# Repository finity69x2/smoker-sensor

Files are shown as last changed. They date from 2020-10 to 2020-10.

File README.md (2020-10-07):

# Smoker Sensor

This is a sensor that will read both the temperature of a smoker box and a single probe for food temperature.

It provides a webpage to display the current temperatures (updates every 10 seconds) along with communication to an MQTT broker for 
accessing the temperatures for my home automation system (Home Assistant).

It's built around a NodeMCU development board because it is lower power and provides wifi on board. It is programmmed using the Arduino-IDE.

The Arduino skecth is included here along with a schematic developed using the Fritzing app.

Here is the parts list:

| Part | Link |
| --- | --- |
| NodeMCU | https://smile.amazon.com/gp/product/B07L8W9SP3 |
| Thermocouple probe | https://smile.amazon.com/gp/product/B07JL1SN7X |
| MAX31855 breakout board for thermocouple | https://smile.amazon.com/gp/product/B07T7WY3H8 |
| panel mount thermocouple connector | https://smile.amazon.com/k-type-thermocouple-miniature-socket-connector/dp/B071SCMHRX |
| thermocouple male connector | https://smile.amazon.com/Twidec-Thermocouple-Connector-Adapter-Temperature/dp/B07PQW47BP |
| thermister probe | https://smile.amazon.com/gp/product/B07L4TQC4B |
| Thermister connector | https://smile.amazon.com/gp/product/B01ASF0GWS |
| LED's | https://smile.amazon.com/gp/product/B01AUI4W5U |
| waterproof box | https://smile.amazon.com/gp/product/B07QGS2HT4 |
| USB Power connectors | https://smile.amazon.com/gp/product/B0183KF7TM |
| capacitors | https://smile.amazon.com/gp/product/B07KRTQGL7 |
| USB extension plug | https://smile.amazon.com/gp/product/B00B5HSC20 |
| perf board | https://smile.amazon.com/gp/product/B07QL77SC5 |
| resistors | https://smile.amazon.com/gp/product/B072BL2VX1 |

You can likely get all of this cheaper on sites like Aliexpress with the attendant longer shipping times.

The sensor serves up a webpage to allow you to see the current temperatues in real time (it updates every 10 seconds) and an MQTT connection to allow you to connect to your home automation system.

I have provided two different Arduino Sketches. One that provides the MQTT connection and one that doesn't. So if you don't have the need to use MQTT then use the latter (non-MQTT) sketch.

You will need to determine the co-erfficients for the thermistor you use and what the nominal resistance is and enter that info into the Arduino sketch. the sketch also allows you to use the Beta value if that has been supplied by the manufacturer. Just uncomment whichever method you will want to use.

After the sketch is flashed to the NodeMCU initial network config is done via an AP (SmokerConnectAP) provided by the NodeMCU. Once connected to the AP then navigate 192.168.1.4 and fill in your credentials.

After the initial config is completed then the sensor will reboot and connect to your wifi network (and MQTT broker if used). You will need to go into your router to find the IP address of the sensor or however you normally find IP addresses of devices on your network.

The sensor has three status LED's - One for Power (green), One for Wifi connection status (blue) and an activity LED (red).

It uses a thermistor for measuring the food temperature and a K-type thermocouple for the smoker box temerature measurement.

Here is the schematic:

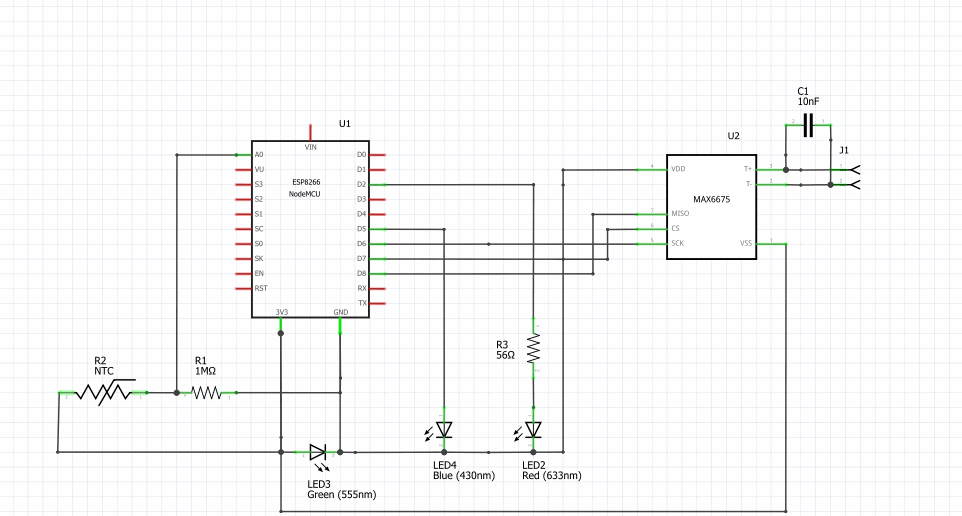
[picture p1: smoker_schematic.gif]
Schematic


Here are the pictures of the end result:

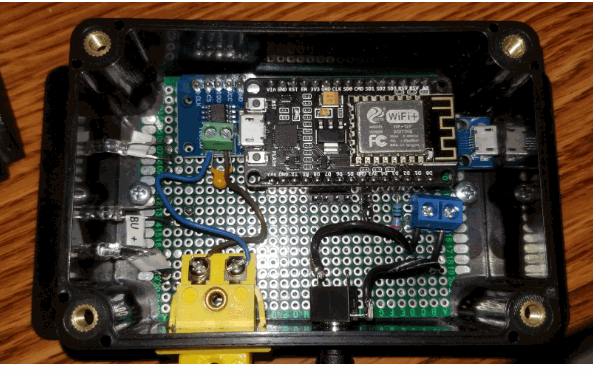
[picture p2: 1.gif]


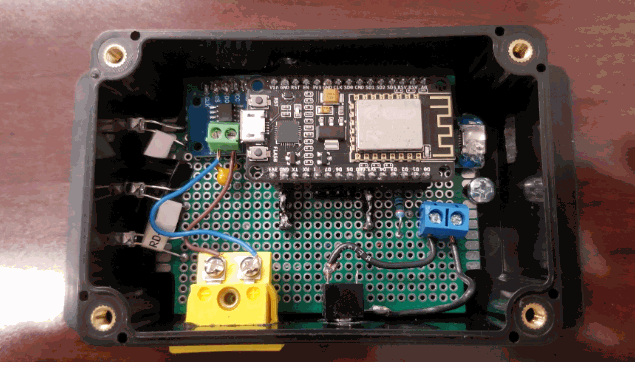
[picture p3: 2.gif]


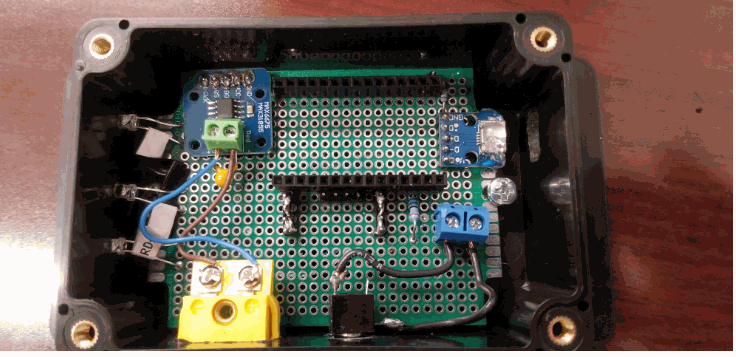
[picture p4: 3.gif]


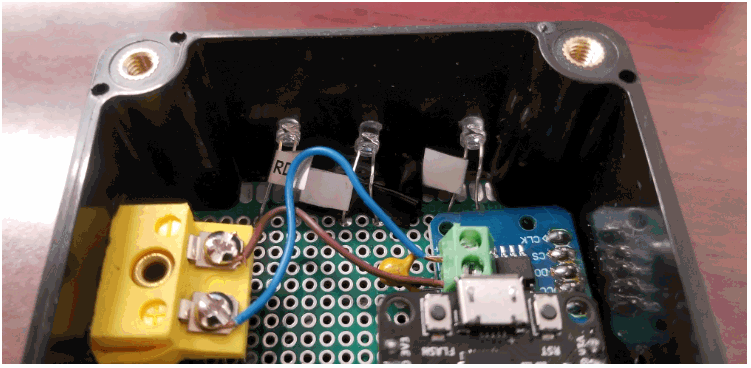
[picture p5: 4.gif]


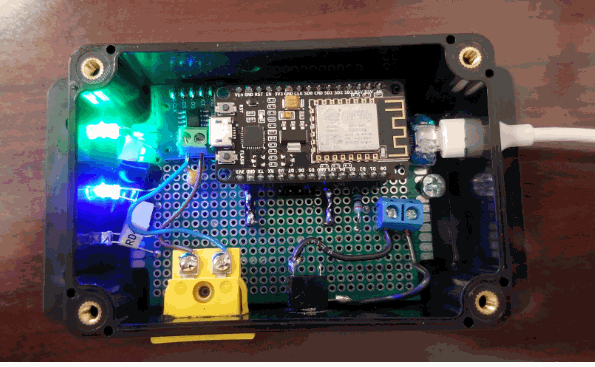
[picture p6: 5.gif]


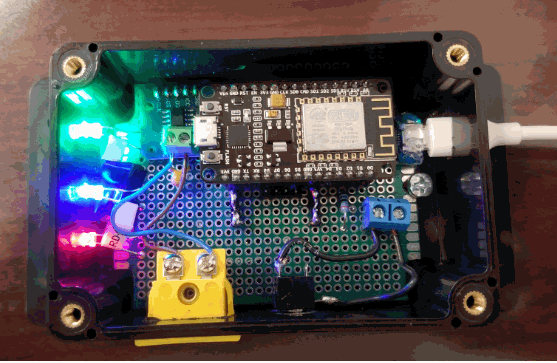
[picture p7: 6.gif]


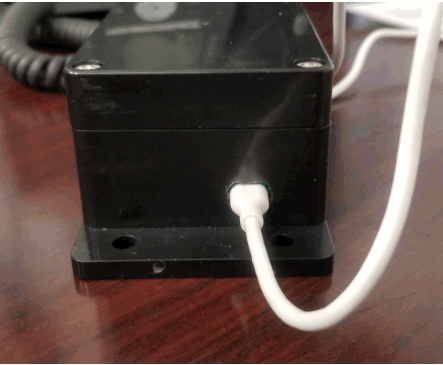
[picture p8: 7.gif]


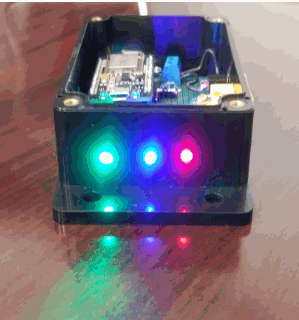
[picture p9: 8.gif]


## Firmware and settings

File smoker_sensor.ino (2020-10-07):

#include <FS.h>                   //this needs to be first, or it all crashes and burns...

#include <Arduino.h>
#include <ESP8266WiFi.h>          //https://github.com/esp8266/Arduino
#include <DNSServer.h>
#include <ESP8266WebServer.h>
#include <WiFiManager.h>          //https://github.com/tzapu/WiFiManager
#include <Hash.h>
#include <ESPAsyncTCP.h>
#include <ESPAsyncWebServer.h>
#include <Wire.h>
#include <PubSubClient.h>
#include <ArduinoJson.h>          //https://github.com/bblanchon/ArduinoJson
#include "Adafruit_MAX31855.h"

// ------------------- General Setup Code ------------------------------

int ledPinBlue = D5;                // Blue LED connected to digital pin D5 - On when wifi connected
int ledPinRed = D2;                // Red LED connected to digital pin D2 - On when taking a sample (activity indicator)

// Generally, you should use "unsigned long" for variables that hold time
// The value will quickly become too large for an int to store
unsigned long previousMillis = 0;    // will store last time sensor was updated

// Updates probe readings every 10 seconds
const long interval = 10000;  

// used for averaging code
const int SAMPLE_NUMBER = 10;

WiFiClient espClient;
PubSubClient client(espClient);

// ------------------- Thermocouple Setup Code -------------------------

// MAX31855 pins     ESP8266 pins
// GND              GND
// VCC              3.3V
// SCK              GPIO12 (D6)
// CS               GPIO13 (D7)
// SO               GPIO15 (D8)
//
// pin order: (sck, cs, so)
Adafruit_MAX31855 tSmoker(D6, D7, D8);

// current box temperature, updated in loop()
float ts = 0.0;

double correctedTempF = 0;
double rawTempF = 0;

float TcoupleAve;
float TcoupleAverage  = 0;            // Holds the average voltage measurement
float TcoupleScaledAverage = 0;       // Holds Scaled value of Cm reading after Offset applied
float TcoupleTotal = 0;               // Total of all Cm readings in averaging code
int   TcoupleSamples[SAMPLE_NUMBER];  // Array to hold each voltage measurement
const float TcOffset = 1.0;           // If Needed


// -------------------- Thermistor B Setup Code ------------------------

// visit here for calculating the Co-efficients and Beta Values if not supplied by the vendor
//
// https://www.thinksrs.com/downloads/programs/Therm%20Calc/NTCCalibrator/NTCcalculator.htm
//

// Pin Setup
int ThermistorPin = A0;

// Constants
const float Cmax = 1024.102; // max counts for analog input pin @ 3.3vdc

// Put your thermister constant values here
const float Rb = 99600.0; // Value of voltage divider resistor
const float Offset = 1.0; // Was .9345 for thermistor A

// Only used if you use the Beta Value for calculation:
//const float Beta = 3936.28; 
//const float Ro = 99406.98; // Ro = Room Temperature (25C/77F) Resistance of the thermister
//const float To = 298.15;   // To = Room Temperature in K (25C/77F) - don't change

// Only used if you use the Steinhart-Hart Coefficients for calculation:
const float C1 = 0.8949830252e-3; // C1 = coefficient A
const float C2 = 1.909803133e-4;  // C2 = coefficient B
const float C3 = 1.688635553e-7;  // C3 = coefficient C

//put your linearization equation constants here
const int HighCutoff = 115; // value above which you use the high linearization equation
const float Mhigh = .26;    // slope value for the high side equation
const float Mlow = .05;     // slope value for the low side equation
const float Bhigh = 38.23;  // y-intercept value for the high side equation
const float Blow = 11.68;   // y-intercept value for the low side equation


// Measured and Calculated Values
float Rmave, logRmave, Tcave, Tfave, TfLinear; //, Tcbeta, Tfbeta;
float CmAverage  = 0;            // Holds the average voltage measurement
float CsAverage = 0;             // Holds Scaled value of Cm reading after Offset applied
float CmTotal = 0;               // Total of all Cm readings in averaging code
int   CmSamples[SAMPLE_NUMBER];  // Array to hold each voltage measurement


// current food temperature, updated in loop()
float tf = 0.0;


// -------------------- WifiManager Setup Code -----------------------

#define TRIGGER_PIN 0     // used to call the WifiManager on-demand

//define your default values here, if there are different values in config.json, they are overwritten.
//bool useMqtt = false;
//char mqtt_server[40];
//char mqtt_port[6];
//char mqtt_user[40];
//char mqtt_password[40];
// NEW ITEMS TO ADD TOPIC PARAMETERS
//char client_name[40];
//char temperature_smoker_topic[40];
//char temperature_food_topic[40];
//char will_topic[40];

//flag for saving data
bool shouldSaveConfig = false;


// -------------------- Webserver Setup Code -------------------------

// Create AsyncWebServer object on port 80
AsyncWebServer server(80);

const char index_html[] PROGMEM = R"rawliteral(
<!DOCTYPE HTML><html>
<head>
  <meta name="viewport" content="width=device-width, initial-scale=1">
  <link rel="stylesheet" href="https://use.fontawesome.com/releases/v5.7.2/css/all.css" integrity="sha384-fnmOCqbTlWIlj8LyTjo7mOUStjsKC4pOpQbqyi7RrhN7udi9RwhKkMHpvLbHG9Sr" crossorigin="anonymous">
  <style>
    html {
     font-family: Arial;
     display: inline-block;
     margin: 0px auto;
     text-align: center;
    }
    h2 { font-size: 3.0rem; }
    p { font-size: 3.0rem; }
    .units { font-size: 1.2rem; }
    .dht-labels{
      font-size: 1.5rem;
      vertical-align:middle;
      padding-bottom: 15px;
    }
  </style>
</head>
<body>
  <h2>Smoker Temperatures</h2>
  <p>
    <i class="fas fa-thermometer-half" style="color:#059e8a;"></i> 
    <span class="dht-labels">Smoker Box Temperature</span> 
  </p>
  <p>
    <span id="box_temp">%BOXTEMP%</span>
    <sup class="units">&deg;F</sup>
  </p>
  <p>
    <i class="fas fa-thermometer-half" style="color:#00add6;"></i> 
    <span class="dht-labels">Food Temperature</span>
  </p>
  <p>
    <span id="food_temp">%FOODTEMP%</span>
    <sup class="units">&deg;F</sup>
  </p>
</body>
<script>
setInterval(function ( ) {
  var xhttp = new XMLHttpRequest();
  xhttp.onreadystatechange = function() {
    if (this.readyState == 4 && this.status == 200) {
      document.getElementById("box_temp").innerHTML = this.responseText;
    }
  };
  xhttp.open("GET", "/box_temp", true);
  xhttp.send();
}, 10000 ) ;

setInterval(function ( ) {
  var xhttp = new XMLHttpRequest();
  xhttp.onreadystatechange = function() {
    if (this.readyState == 4 && this.status == 200) {
      document.getElementById("food_temp").innerHTML = this.responseText;
    }
  };
  xhttp.open("GET", "/food_temp", true);
  xhttp.send();
}, 10000 ) ;
</script>
</html>)rawliteral";

// Replaces placeholder with probe values
String processor(const String& var){
  //Serial.println(var);
  if(var == "BOXTEMP"){
    return String(ts);
  }
  else if(var == "FOODTEMP"){
    return String(tf);
  }
  return String();
}

// ---------------------- Functions -----------------------------

//------ callback notifying us of the need to save config
void saveConfigCallback () {
  Serial.println("Should save config");
  shouldSaveConfig = true;
}

//---------- WIFI AP ------------

void config_ap() {
  // Put wifimanager stuff here....

  digitalWrite(ledPinBlue, LOW);   // sets the LED off
  
  Serial.println();

  //clean FS, for testing
  //SPIFFS.format();

  //read configuration from FS json
  Serial.println("mounting FS...");

  if (SPIFFS.begin()) {
    Serial.println("mounted file system");
    if (SPIFFS.exists("/config.json")) {
      //file exists, reading and loading
      Serial.println("reading config file");
      File configFile = SPIFFS.open("/config.json", "r");
      if (configFile) {
        Serial.println("opened config file");
        size_t size = configFile.size();
        // Allocate a buffer to store contents of the file.
        std::unique_ptr<char[]> buf(new char[size]);

        configFile.readBytes(buf.get(), size);
        DynamicJsonBuffer jsonBuffer;
        JsonObject& json = jsonBuffer.parseObject(buf.get());
        json.printTo(Serial);
        if (json.success()) {
          Serial.println("\nparsed json");

          //useMqtt = json["useMqtt"];
          //strcpy(mqtt_server, json["mqtt_server"]);
          //strcpy(mqtt_port, json["mqtt_port"]);
          //strcpy(mqtt_user, json["mqtt_user"]);
          //strcpy(mqtt_password, json["mqtt_password"]);
          // NEW PARAMETERS FOR MQTT TOPICS
          //strcpy(client_name, json["client_name"]);
          //strcpy(temperature_smoker_topic, json["temperature_smoker_topic"]);
          //strcpy(temperature_food_topic, json["temperature_food_topic"]);
          //strcpy(will_topic, json["will_topic"]);
          
          

        } else {
          Serial.println("failed to load json config");
        }
        configFile.close();
      }
    }
  } else {
    Serial.println("failed to mount FS");
  }
  //end read

  //set up check box
  //char customhtml[24] = "type=\"checkbox\"";
  //  if (useMqtt) {
  //    strcat(customhtml, " checked");
  //  }

  // The extra parameters to be configured (can be either global or just in the setup)
  // After connecting, parameter.getValue() will get you the configured value
  // id/name placeholder/prompt default length
  //WiFiManagerParameter custom_use_mqtt("use_mqtt", "use mqtt", "T", 2, customhtml, WFM_LABEL_AFTER);
  //WiFiManagerParameter custom_mqtt_server("server", "mqtt server", mqtt_server, 40);
  //WiFiManagerParameter custom_mqtt_port("port", "mqtt port", mqtt_port, 6);
  //WiFiManagerParameter custom_mqtt_user("mqtt_username", "mqtt user", mqtt_user, 40);
  //WiFiManagerParameter custom_mqtt_password("mqtt_password", "mqtt password", mqtt_password, 40);
  // NEW PARAMETERS FOR MQTT TOPICS
  //WiFiManagerParameter custom_client_name("client_name", "client_name", client_name, 40);  
  //WiFiManagerParameter custom_temperature_smoker_topic("temperature_smoker_topic", "temperature smoker topic", temperature_smoker_topic, 40);  
  //WiFiManagerParameter custom_temperature_food_topic("temperature_food_topic", "temperature food topic", temperature_food_topic, 40);  
  //WiFiManagerParameter custom_will_topic("will_topic", "will topic", will_topic, 40);
  
  
  //WiFiManager
  //Local intialization. Once its business is done, there is no need to keep it around
  WiFiManager wifiManager;

  //set config save notify callback
  wifiManager.setSaveConfigCallback(saveConfigCallback);

  //set static ip
  //wifiManager.setSTAStaticIPConfig(IPAddress(10,0,1,99), IPAddress(10,0,1,1), IPAddress(255,255,255,0));
  
  //add all your parameters here
  //wifiManager.addParameter(&custom_use_mqtt);
  //wifiManager.addParameter(&custom_mqtt_server);
  //wifiManager.addParameter(&custom_mqtt_port);
  //wifiManager.addParameter(&custom_mqtt_user);
  //wifiManager.addParameter(&custom_mqtt_password);
  // NEW PARAMETERS FOR MQTT TOPICS
  //wifiManager.addParameter(&custom_client_name);  
  //wifiManager.addParameter(&custom_temperature_smoker_topic);  
  //wifiManager.addParameter(&custom_temperature_food_topic);  
  //wifiManager.addParameter(&custom_will_topic);
  
  

  //reset settings - for testing
  //wifiManager.resetSettings();

  //set minimu quality of signal so it ignores AP's under that quality
  //defaults to 8%
  //wifiManager.setMinimumSignalQuality();
  
  //sets timeout until configuration portal gets turned off
  //useful to make it all retry or go to sleep
  //in seconds
  //wifiManager.setTimeout(120);

  //fetches ssid and pass and tries to connect
  //if it does not connect it starts an access point with the specified name
  //here  "AutoConnectAP"
  //and goes into a blocking loop awaiting configuration
  if (!wifiManager.autoConnect("SmokerConnectAP")) {
    Serial.println("failed to connect and hit timeout");
    delay(3000);
    //reset and try again, or maybe put it to deep sleep
    ESP.reset();
    delay(5000);
  }

  //if you get here you have connected to the WiFi
  Serial.println("connected...yeey :)");
  digitalWrite(ledPinBlue, HIGH);   // sets the LED on
  Serial.println("blue light on");

  //read updated parameters
  //useMqtt = (strncmp(custom_use_mqtt.getValue(), "T", 1) == 0);
  //useMqtt = custom_use_mqtt.getValue();
  //strcpy(mqtt_server, custom_mqtt_server.getValue());
  //strcpy(mqtt_port, custom_mqtt_port.getValue());
  //strcpy(mqtt_user, custom_mqtt_user.getValue());
  //strcpy(mqtt_password, custom_mqtt_password.getValue());
  // NEW PARAMETERS FOR MQTT TOPICS
  //strcpy(client_name, custom_client_name.getValue());  
  //strcpy(temperature_smoker_topic, custom_temperature_smoker_topic.getValue());  
  //strcpy(temperature_food_topic, custom_temperature_food_topic.getValue());  
  //strcpy(will_topic, custom_will_topic.getValue());
  
  
  //save the custom parameters to FS
  if (shouldSaveConfig) {
    Serial.println("saving config");
    DynamicJsonBuffer jsonBuffer;
    JsonObject& json = jsonBuffer.createObject();
    //json["use_mqtt"] = useMqtt;
    //json["mqtt_server"] = mqtt_server;
    //json["mqtt_port"] = mqtt_port;
    //json["mqtt_user"] = mqtt_user;
    //json["mqtt_password"] = mqtt_password;
    // NEW PARAMETERS FOR MQTT TOPICS
    //json["client_name"] = client_name;    
    //json["temperature_smoker_topic"] = temperature_smoker_topic;    
    //json["temperature_food_topic"] = temperature_food_topic;    
    //json["will_topic"] = will_topic;
      

    File configFile = SPIFFS.open("/config.json", "w");
    if (!configFile) {
      Serial.println("failed to open config file for writing");
    }

    json.printTo(Serial);
    json.printTo(configFile);
    configFile.close();
    //end save
  }

  Serial.println("local ip");
  Serial.println(WiFi.localIP());

}

//------------ SETUP CODE (RUN ONCE) -------------

void setup() {
  // put your setup code here, to run once:
  pinMode(ledPinBlue, OUTPUT);
  pinMode(ledPinRed, OUTPUT);
  pinMode(TRIGGER_PIN, INPUT);
  
  Serial.begin(115200);

  config_ap();
 
  // Route for root / web page
  server.on("/", HTTP_GET, [](AsyncWebServerRequest *request){
    request->send_P(200, "text/html", index_html, processor);
  });
  server.on("/box_temp", HTTP_GET, [](AsyncWebServerRequest *request){
    request->send_P(200, "text/plain", String(ts).c_str());
  });
  server.on("/food_temp", HTTP_GET, [](AsyncWebServerRequest *request){
    request->send_P(200, "text/plain", String(tf).c_str());
  });

  // Start server
  server.begin();
  Serial.println("Server started");

  //unsigned int mqtt_port_int = atoi (mqtt_port);

  //client.setServer(mqtt_server, mqtt_port_int);

}

/*
//---------- MQTT CONNECTION -------------------

void reconnect() {
   // Loop until we're reconnected
   while (!client.connected()) {
      Serial.print("Attempting MQTT connection…");

      // Generate client name based on MAC address and last 8 bits of microsecond counter
      //  String clientName;  
      //  clientName += "esp8266-";
      //  uint8_t mac[6];
      //  WiFi.macAddress(mac);
      //  clientName += macToStr(mac);
      //  clientName += "-";  
      //  clientName += String(micros() & 0xff, 16);
      Serial.print("Connecting to ");
      Serial.print(mqtt_server);
      Serial.print(" as ");
      Serial.println(client_name);

      // Attempt to connect
      // If you do not want to use a username and password, change next line to
      //if (client.connect((char*) clientName.c_str())) {
      //if (client.connect("homeassistant","homeassistant","05081985"))
      //if (client.connect("ESP8266Client", mqtt_user, mqtt_password))
      if (client.connect(client_name, mqtt_user, mqtt_password, will_topic, 1, 1, "Offline")){
         Serial.println("connected");
      } 
      else {
         Serial.print("failed, rc=");
         Serial.print(client.state());
         Serial.println(" try again in 5 seconds");
         // Wait 5 seconds before retrying
         delay(5000);
         // is configuration portal requested?
         if ( digitalRead(TRIGGER_PIN) == LOW ) {
           //digitalWrite(ledPinBlue, LOW);   // sets the LED off
           //reset settings - for testing
           WiFiManager wifiManager;
           wifiManager.resetSettings();
           config_ap();
        }
      }
   }

   client.publish(will_topic, "Online", true);
}
*/

//---------- MAIN PROGRAM LOOP -------------
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
